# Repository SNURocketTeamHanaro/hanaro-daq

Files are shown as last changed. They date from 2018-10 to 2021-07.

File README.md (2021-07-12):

# Hanaro DAQ
A simple, low-cost, crude data acquisition system for combustion test of solid rocket motor.

### Specification
Hanaro DAQ for 200kgf horizontal combustion test system is a super low-cost data acquisition system. Equipped with two transducer for pressure sensor on the left and right side of the chamber top, and an instrumental amplifier for a single 200kgf load cell. Data is retrieved and recorded every 6-7 ms.

### Contents
- Hanaro DAQ PCB board designed with KiCAD v5.0.0
- Simple Arduino code for acquisition of data
- Data acquired with the system

### Credit
[Jaerin Lee](https://github.com/ironjr)  
Lead Electronics and Software Developer  
SNU Rocket Team Hanaro

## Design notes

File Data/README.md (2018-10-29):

# Solid Rocket Motor Combustion Test Data
The data is arranged in folders named by format:
    YYMMDD-_Propellant Name_-_Nozzle Diameter_
KNSB is abbreviation for [Potassium Nitrate/Sorbitol](https://www.nakka-rocketry.net/sorb.html) rocket propellant.  
ANCP is abbreviation for [Ammonium Nitrate/Aluminum](https://www.nakka-rocketry.net/anexp.html) rocket propellant.  
For more info, please visit [Richard Nakka's home page](https://www.nakka-rocketry.net/).

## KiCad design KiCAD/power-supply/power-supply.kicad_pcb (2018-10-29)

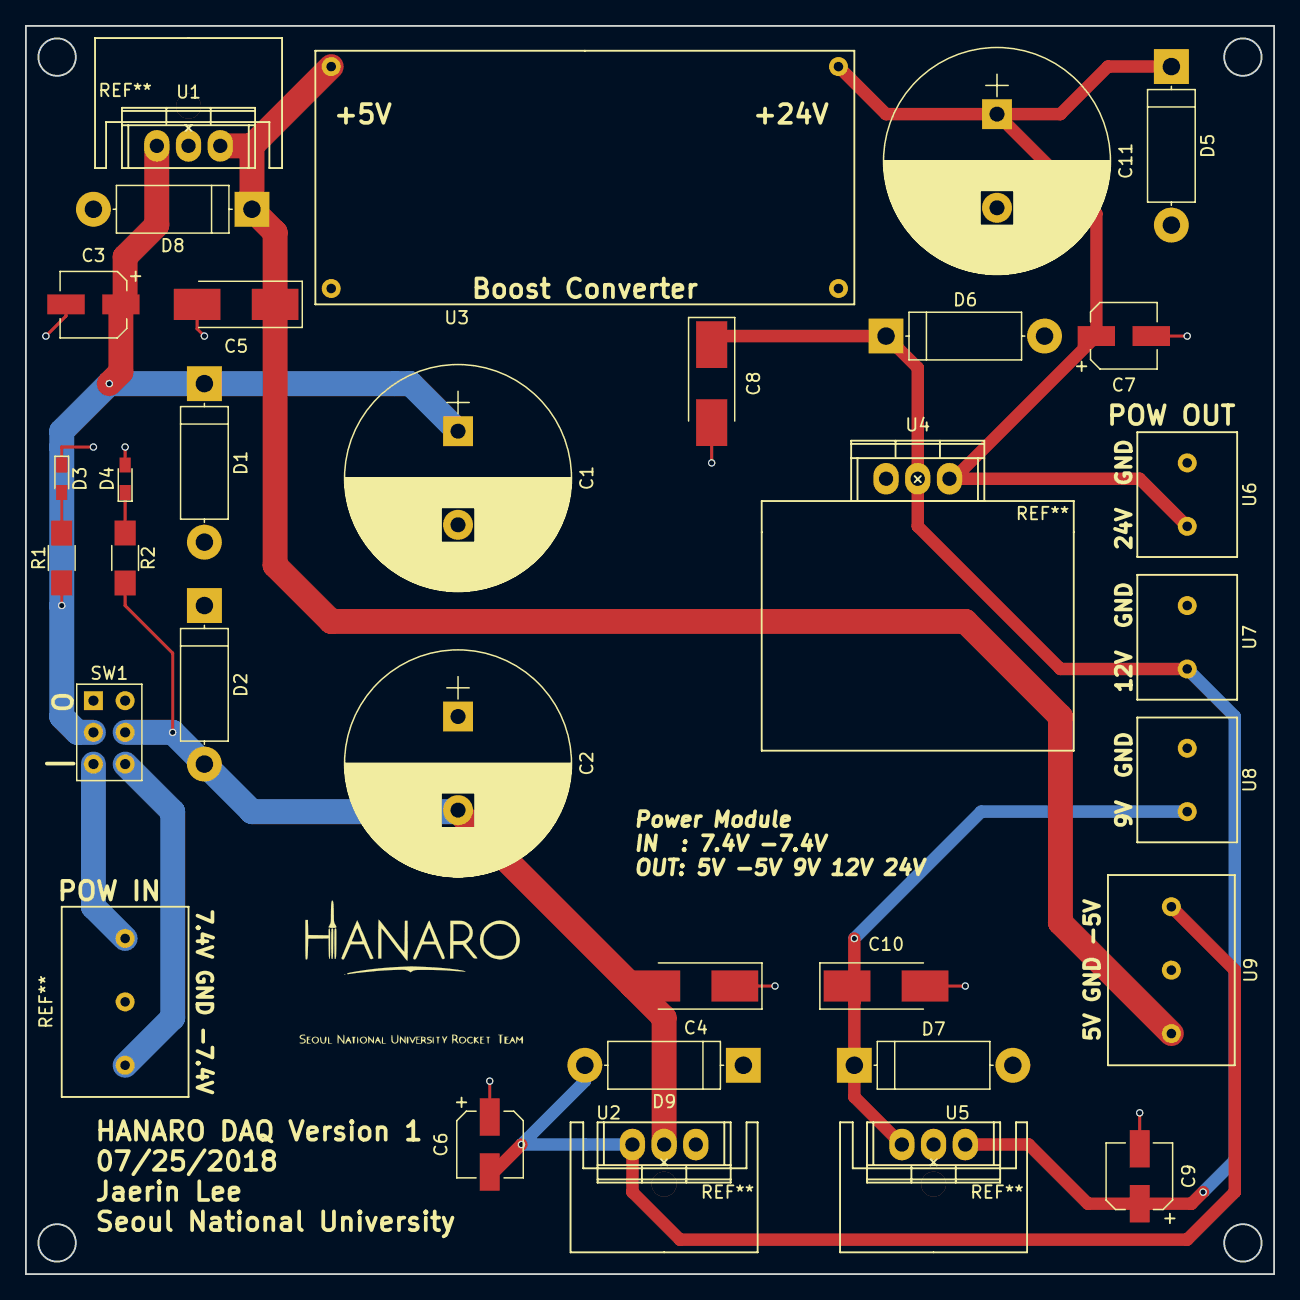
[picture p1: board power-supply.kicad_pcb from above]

Board: 2 copper layers, 100.0 x 100.0 mm, 32 parts (0 on the bottom side), 10 nets.

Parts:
C1, C2, C11: CP1; CP_Radial_D18.0mm_P7.50mm
C3, C6, C7, C9: CP1; CP_Elec_5x5.3
C4, C5, C8, C10: CP1; CP_Tantalum_Case-C_EIA-6032-28_Hand
D1, D2, D5, D6, D7, D8, D9: D; D_5W_P12.70mm_Horizontal
D3, D4: LED; LED_0603_HandSoldering
R1, R2: R; R_1206_HandSoldering
SW1: SW_DPDT_x2; SW_NKK_G1xJP
U1: L7805; TO-220
U2: L7905; TO-220
U3: BoostConv; Boost.Conv
U4: LM1085-12; TO-220
U5: L7809; TO-220
U6, U7, U8: Conn2; Connector.2pin
U9: Conn3; Connector.3pin

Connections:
/V5out: C5.1, D8.1, U1.3, U3.1, U9.1
/V9out: C10.1, D7.1, U5.3, U8.1
/V12out: C8.1, C9.1, D6.1, U4.2, U5.1, U7.1
/V24out: C7.1, C11.1, D5.1, U3.3, U4.3, U6.1
/V-5out: C6.2, D9.2, U2.3, U9.3
GND: C1.2, C2.1, C3.2, C4.1, C5.2, C6.1, C7.2, C8.2, C9.2, C10.2, C11.2, D1.2, D2.1, D3.1, D4.2, D5.2, D6.2, D7.2, D8.2, D9.1, U1.2, U2.1, U3.2, U3.4, U4.1, U5.2, U6.2, U7.2, U8.2, U9.2
unnamed: C1.1, C3.1, D1.1, R1.1, SW1.2, U1.1
unnamed: C2.2, C4.2, D2.2, R2.2, SW1.5, U2.2
unnamed: D3.2, R1.2
unnamed: D4.1, R2.1

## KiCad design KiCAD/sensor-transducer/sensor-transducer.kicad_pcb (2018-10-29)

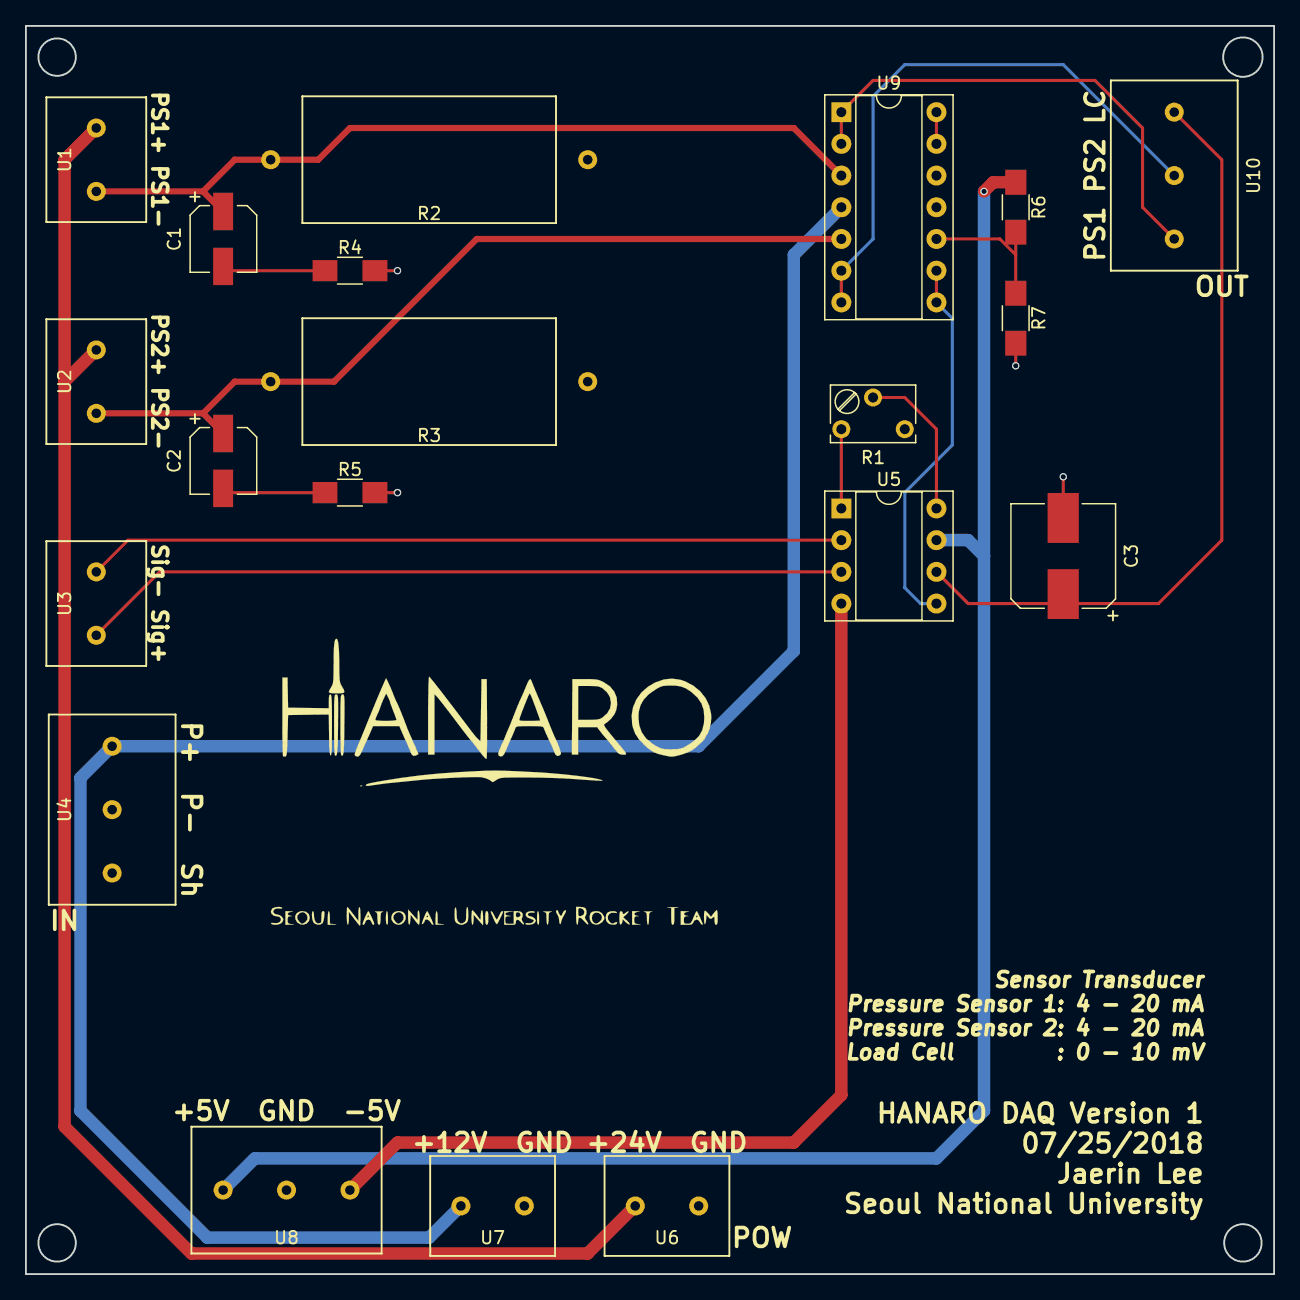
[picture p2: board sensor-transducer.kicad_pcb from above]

Board: 2 copper layers, 100.0 x 100.0 mm, 20 parts (0 on the bottom side), 19 nets.

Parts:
C1, C2: CP1; CP_Elec_5x5.3
C3: CP1; CP_Elec_8x10
R1: R_Variable; Potentiometer_Trimmer_Bourns_3266W
R2, R3: R; Register.Cement.Square.Large
R4, R5, R6, R7: R; R_1206_HandSoldering
U1, U2, U3, U6, U7: Conn2; Connector.2pin
U4, U8, U10: Conn3; Connector.3pin
U5: AD620; DIP-8_W7.62mm_Socket
U9: LM324; DIP-14_W7.62mm_Socket

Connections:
+5V: R6.1, U5.7, U8.1
+12V: U4.1, U7.1, U9.4
-9VA: U5.4, U8.3
/24V+: U1.1, U2.1, U6.1
/AD620Ref: U5.5, U9.8, U9.9
/LCSig+: U3.2, U5.3
/LCSig-: U3.1, U5.2
/LCout: C3.1, U5.6, U10.3
/PS1-: C1.1, R2.1, U1.2, U9.3
/PS1out: U9.1, U9.2, U10.1
/PS2-: C2.1, R3.1, U2.2, U9.5
/PS2out: U9.6, U9.7, U10.2
GND: C3.2, R2.2, R3.2, R4.2, R5.2, R7.2, U4.2, U4.3, U6.2, U7.2, U8.2, U9.11
unnamed: C1.2, R4.1
unnamed: C2.2, R5.1
unnamed: R1.1, U5.1
unnamed: R1.2, U5.8
unnamed: R6.2, R7.1, U9.10
unnamed: U9.13, U9.14

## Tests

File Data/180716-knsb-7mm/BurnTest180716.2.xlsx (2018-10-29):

0 | 273 | 281 | 119 | 4.048004289 | 4.164098065 | -0.04003520726 | 0.07038955804 | 0.7497799546 | 1.439934738 | 581.0546875 | -0.4475911458 |  | pressure |  | ad620 offset | ad620 gain
6 | 273 | 275 | 121 | 4.048004289 | 4.075184939 | -0.04003520726 | -0.01852356791 | 0.7497799546 | 0.8842277006 | 590.8203125 | -0.04069010417 | resister | 329.3 | 329.5 | 591.796875 | 200
12 | 272 | 273 | 121 | 4.033176435 | 4.045547231 | -0.0548630618 | -0.04816127656 | 0.6571058638 | 0.6989920215 | 590.8203125 | -0.04069010417 | offset | 4.088039497 | 4.093708507
17 | 273 | 274 | 121 | 4.048004289 | 4.060366085 | -0.04003520726 | -0.03334242223 | 0.7497799546 | 0.7916098611 | 590.8203125 | -0.04069010417 | position | left | right | (bottom nozzle)
23 | 273 | 274 | 122 | 4.048004289 | 4.060366085 | -0.04003520726 | -0.03334242223 | 0.7497799546 | 0.7916098611 | 595.703125 | 0.1627604167
29 | 284 | 286 | 120 | 4.211110689 | 4.238192337 | 0.1230711927 | 0.1444838297 | 1.769194954 | 1.903023935 | 585.9375 | -0.244140625
34 | 272 | 276 | 122 | 4.033176435 | 4.090003794 | -0.0548630618 | -0.003704713581 | 0.6571058638 | 0.9768455401 | 595.703125 | 0.1627604167
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

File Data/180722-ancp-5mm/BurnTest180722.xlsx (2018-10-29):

0 | 183 | 194 | 251 | 4.063459243 | 4.292096171 | -0.08682035869 | 0.2258881542 | 0.4573727582 | 2.411800964 | 1225.585938 | -2.482096354 |  | pressure |  | ad620 offset | ad620 gain
6 | 183 | 180 | 209 | 4.063459243 | 3.982357272 | -0.08682035869 | -0.08385074479 | 0.4573727582 | 0.4759328451 | 1020.507812 | -11.02701823 | resister | 219.9 | 220.7 | 1285.15625 | 200
12 | 183 | 181 | 248 | 4.063459243 | 4.004481479 | -0.08682035869 | -0.06172653772 | 0.4573727582 | 0.6142091392 | 1210.9375 | -3.092447917 | offset | 4.150279602 | 4.066208017
17 | 185 | 181 | 269 | 4.107868633 | 4.004481479 | -0.04241096805 | -0.06172653772 | 0.7349314497 | 0.6142091392 | 1313.476562 | 1.180013021 | position | left | right | (bottom nozzle)
23 | 208 | 182 | 285 | 4.618576626 | 4.026605686 | 0.4682970242 | -0.03960233065 | 3.926856401 | 0.7524854334 | 1391.601562 | 4.435221354
29 | 183 | 190 | 266 | 4.063459243 | 4.203599343 | -0.08682035869 | 0.1373913259 | 0.4573727582 | 1.858695787 | 1298.828125 | 0.5696614583
34 | 184 | 181 | 251 | 4.085663938 | 4.004481479 | -0.06461566337 | -0.06172653772 | 0.5961521039 | 0.6142091392 | 1225.585938 | -2.482096354
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

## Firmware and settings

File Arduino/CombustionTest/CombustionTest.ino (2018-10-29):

/***************************************************************************
   Filename       : CombustionTest.ino
   Target machine : Arduino Uno

   Contributor    :
          rev.1 @ 2018. 07. 04.
                HANARO, SNU.
                Jaerin Lee
 ***************************************************************************/

#include <stdio.h>
//#include <SD.h>
#include <SPI.h>
#include "SdFat.h"

#define PRESSURE0 A0
#define PRESSURE1 A1
#define LOADCELL0 A3

#define INIT_DATA_DUMP_COUNT 10
#define INIT_DATA_AVG_COUNT 20

#define PERIOD_DATA_RETRIEVAL 5 // ms
#define MAX_DATA_NUM 10
#define SAVE_CYCLE 5

/*
struct data_packet_t {
  uint32_t current_time; // 4
  uint16_t pressure0;    // 2
  uint16_t pressure1;    // 2
  uint16_t loadcell0;    // 2
};

typedef union data_t {
  struct data_packet_t data_packet;
  char data_packet_string[sizeof(struct data_packet_t)];
  byte data_packet_bytestring[sizeof(struct data_packet_t)];
};

data_t data[MAX_DATA_NUM];
uint32_t datanum = 0;
*/

uint32_t save_cycle = 0;

SdFat SD;
File file_sd;
char file_name[50] = "data.txt";
char data_string[50];

/*
uint32_t curr_time;
uint32_t prev_time = 0;
*/

void setup() {
  pinMode(6, OUTPUT);
  digitalWrite(6, LOW);

  Serial.begin(115200);
  Serial.println("[  WORK] Initiate device configuration.");
  memset(data_string, '\0', sizeof(char) * 50);

/*
  while (1) {
    if (!SD.begin()) {
      digitalWrite(6, HIGH);
      Serial.println("[ ERROR] Device error: SD card.");
    } else {
      // Open a new file
      //memset(file_name, '\0', sizeof(char) * 50);
      //sprintf(file_name, "%d.txt", millis());
      file_sd = SD.open(file_name, FILE_WRITE); //O_CREAT | O_WRITE);
      file_sd.close();
      Serial.print("[STATUS] File opened: ");
      Serial.println(file_name);

      Serial.println("[STATUS] Start logging ...");
      break;
    }
  }
  */
}

void loop() {
  while (1) {
    uint32_t curr_time = millis();
    int pressure0 = analogRead(PRESSURE0);
    int pressure1 = analogRead(PRESSURE1);
    int loadcell0 = analogRead(LOADCELL0);
    sprintf(data_string, "%lu\t%d\t%d\t%d", curr_time, pressure0, pressure1, loadcell0);
    //float pressure0_val = 1.0f + ((((float)pressure0 / 1024) * 5.0f / 0.3254f) - 4) * 100 / 16;
    //float pressure1_val = 1.0f + ((((float)pressure0 / 1024) * 5.0f / 0.3254f) - 4) * 100 / 16;
    //float loadcell0_val = (((loadcell0 / 1024) * 5000.0f) - 34.9) / 4728.72 * 200;
    //sprintf(data_string, "%lu\t%f\t%f\t%f", curr_time, pressure0_val, pressure1_val, loadcell0_val);
    /*
    file_sd = SD.open(file_name, FILE_WRITE); //O_CREAT | O_WRITE);
    file_sd.println(data_string);
    file_sd.close();
    */
    Serial.println(data_string);
    //++save_cycle;
    //if (save_cycle >= SAVE_CYCLE) {
    //  save_cycle = 0;
    //  file_sd.close();
    //  file_sd = SD.open(file_name, FILE_WRITE); //O_CREAT | O_WRITE);
    //}
    delayMicroseconds(PERIOD_DATA_RETRIEVAL * 1000);
  }

  /*
  curr_time = millis();
  if (curr_time - prev_time >= PERIOD_DATA_RETRIEVAL) {
    prev_time = curr_time;

    // Package remaining data
    data[datanum].data_packet.current_time = curr_time;
    data[datanum].data_packet.pressure0 = analogRead(PRESSURE0);
    data[datanum].data_packet.pressure1 = analogRead(PRESSURE1);
    data[datanum].data_packet.loadcell0 = analogRead(LOADCELL0);

    // Next data
    ++datanum;
  }
  */

/*
  if (datanum == MAX_DATA_NUM - 1) {
    // Assume no problem with either the SD card or the connection

    // Write the whole data
    for (uint32_t i = 0; i < datanum; ++i) {
      file_sd.write('$'); // Start character
      file_sd.write('$'); // Start character
      file_sd.write(data[i].data_packet_bytestring, sizeof(struct data_packet_t));
      file_sd.write('#'); // End character
      file_sd.write('#'); // End character 
    }

    // Reset data buffer; go closer to the next saving cycle
    datanum = 0;
    ++save_cycle;

    // Save the file into the SD card
    if (save_cycle >= SAVE_CYCLE) {
      save_cycle = 0;

      file_sd.close();
      file_sd = SD.open(file_name, FILE_WRITE); //O_CREAT | O_WRITE);

      Serial.print("[STATUS] Data saved at ");
      Serial.print(millis());
      Serial.println("ms.");
    }
  }
  */
}

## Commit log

2018-10-29 Current progress on data processing.
    [BurnTest180716.2.xlsx, BurnTest180722.xlsx, BurnTest180724.xlsx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]
2018-10-29 added KiCAD PCB designs
    [power-supply.kicad_pcb, power-supply.sch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]
